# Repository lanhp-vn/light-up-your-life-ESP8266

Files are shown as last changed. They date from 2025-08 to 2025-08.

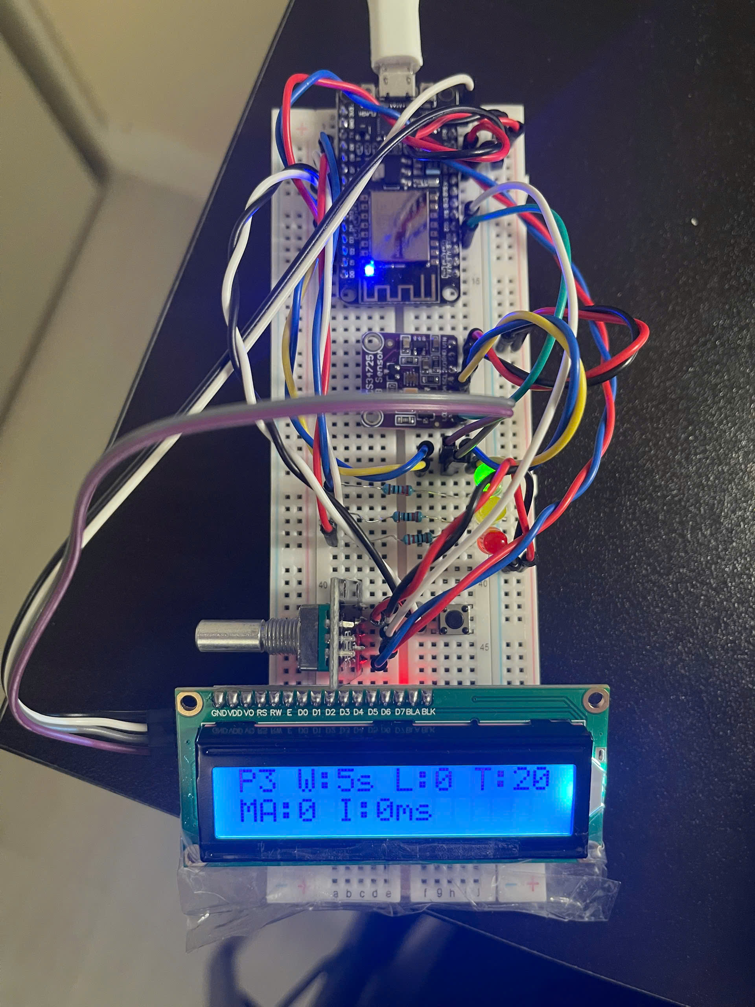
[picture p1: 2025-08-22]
Assembly.jpg

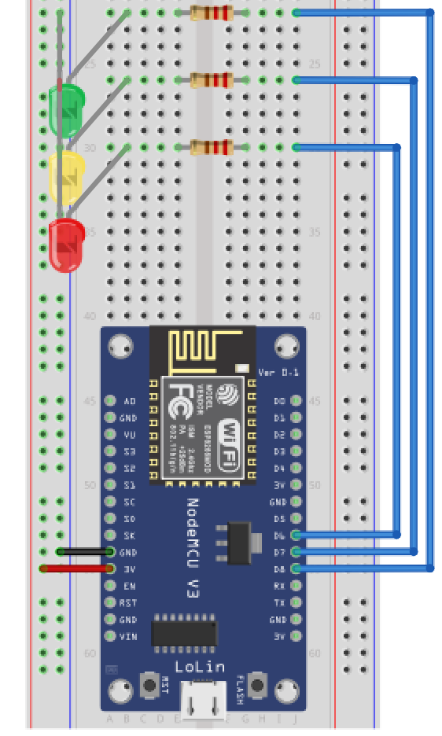
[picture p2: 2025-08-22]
Schematic/schematic_part2.png

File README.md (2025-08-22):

## Light Up Your Life (ESP8266 + TCS34725)

A multi-part IoT lab using ESP8266, Adafruit TCS34725 color/light sensor, LEDs, I2C LCD, and a rotary encoder to visualize ambient light levels and interactively tune thresholds.

Watch the demo video: [YouTube](https://youtu.be/NDT4jKHE5MQ)

### Hardware

- ESP8266 NodeMCU
- Adafruit TCS34725 RGB/clear light sensor (I2C)
- 16x2 I2C LCD (address 0x27)
- 3 x LEDs (red, yellow, green) + resistors
- 1 x momentary button
- 1 x rotary encoder with push button
- Jumper wires, breadboard

I2C bus (shared by TCS34725 and LCD):
- SCL: GPIO5 (D1)
- SDA: GPIO4 (D2)

Other connections (as used in sketches):
- Sensor LED control (`TCS_LED`): GPIO10 (FullAssembly/Part1/Part3) or GPIO0 (Part2)
- Built-in ESP LED: GPIO2 (D4) (Part3)
- Status LEDs: red=GPIO12 (D6), yellow=GPIO13 (D7), green=GPIO15 (D8)
- LCD: I2C @ 0x27 (SCL/SDA as above)
- User button (LCD/part switch): GPIO14 (D5) with INPUT_PULLUP
- Rotary encoder: CLK=GPIO2 (D4), DT=GPIO0 (D3), SW=GPIO9 (encoder push, INPUT_PULLUP)

Note: Pin choices reflect the provided sketches. On some ESP8266 boards, GPIO9/10 are SDIO pins and may be constrained. If your board does not expose them, remap to available GPIOs and update the constants accordingly.

### Project Structure

- `ArduinoSketches/Part1/Part1.ino`: Average lux over a window; drive sensor LED above threshold
- `ArduinoSketches/Part2/Part2.ino`: Classify lux into LOW/MEDIUM/HIGH; drive RGB LEDs; average window drives sensor LED
- `ArduinoSketches/Part3/Part3.ino`: Adds moving average and LED flashing rate proportional to lux; uses built-in LED to reflect average
- `ArduinoSketches/FullAssembly/FullAssembly.ino`: Integrates LCD, encoder, button to switch modes and adjust thresholds live

### Procedure

Common setup for all parts:
1. Wire I2C SCL to GPIO5 (D1), SDA to GPIO4 (D2). Power TCS34725 with 3.3V and GND.
2. If using external LEDs, connect each via a resistor to GPIO12/13/15, with common ground.
3. If using LCD, connect to the same I2C bus (address 0x27).
4. Wire the user button from GPIO14 to GND; enable `INPUT_PULLUP` in code.
5. Wire encoder CLK to GPIO2, DT to GPIO0, and SW to GPIO9 with pull-ups.

Per sketch:
- Part 1 (`Part1.ino`):
  - Window: 5 s, sample every 1 s. Threshold: 40 lux.
  - Action: Sensor LED (`TCS_LED`) turns ON if average lux ≥ threshold.
  - Observe: Serial prints Lux and Avg Lux.

- Part 2 (`Part2.ino`):
  - Thresholds: LOW ≤ 20, HIGH ≥ 70 (MEDIUM in between).
  - Actions: Green/Yellow/Red LEDs indicate LOW/MEDIUM/HIGH. Average window still controls `TCS_LED` at 40 lux.
  - Observe: Serial prints Lux and level (LOW/MEDIUM/HIGH).

- Part 3 (`Part3.ino`):
  - Adds moving average over 5 s; computes LED flash interval linearly between two points: (lux=20 → 1050 ms) and (lux=150 → 10 ms).
  - Actions: Built-in LED reflects average threshold crossing; `TCS_LED` flashes faster with higher lux when moving average > threshold.
  - Observe: Serial prints window, thresholds, Lux, Avg Lux, Moving Avg, Flash interval.

- Full Assembly (`FullAssembly.ino`):
  - LCD shows mode, window, threshold, lux, moving average, and flash interval.
  - Button on GPIO14 cycles Part 1 → 2 → 3.
  - Encoder rotates to adjust `Y_threshold` (0–100) and press to reset to base value (20).
  - Actions from Part 1–3 apply as above, with live threshold tuning.

### Expected Results

- Increasing ambient light raises measured lux. When the average over the 5 s window exceeds the configured threshold, indicator LEDs and/or the built-in LED respond accordingly.
- In Part 2, the color of the external LEDs changes to indicate LOW/MEDIUM/HIGH ranges.
- In Part 3 and Full Assembly, the sensor LED flash rate decreases (faster flashing) as lux increases, following a linear mapping between the defined points.
- The LCD in Full Assembly provides at-a-glance status, and the encoder enables on-the-fly threshold adjustment.

### Build & Upload

1. Open the desired `*.ino` in Arduino IDE (ESP8266 board package installed).
2. Select your ESP8266 board and COM port.
3. Install required libraries:
   - Adafruit TCS34725
   - Adafruit BusIO (dependency providing `Adafruit_I2CDevice.h`)
   - LiquidCrystal_I2C
4. Upload and open Serial Monitor at 115200 baud.

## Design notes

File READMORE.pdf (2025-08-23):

## EQUIPMENT LIST

Items | Model | Quantity | Power Supply
NodeMCU ESP8266 | ESP8266-12E | 1 | 4.5 to 9 VDC
RGB Color Sensor | TCS34725 | 1 | 3.3 to 5 VDC
Light Emitting Diode | 5mm Red/Yellow/Green LEDs | 3 | With resistors
Resistor | 220 Ω | 3
Push Button | Bread-board Mount | 1
Liquid-Crystal Display | I2C 1602 Serial LCD Module | 1 | 5VDC
Rotary Encoder | KY-040 | 1 | 5VDC
Table 1. Equipment list

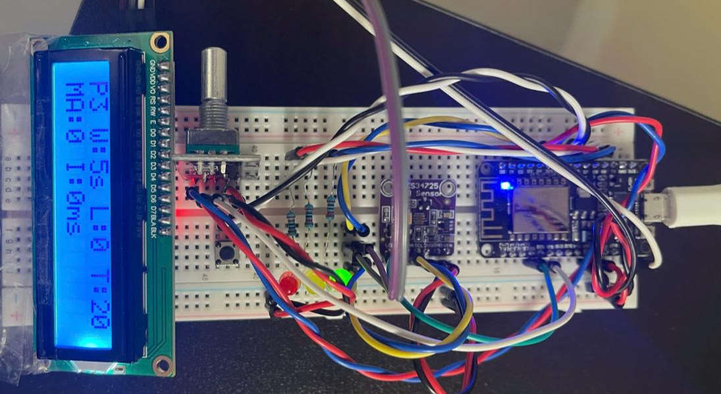
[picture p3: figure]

Figure 1. Assembly of all equipment

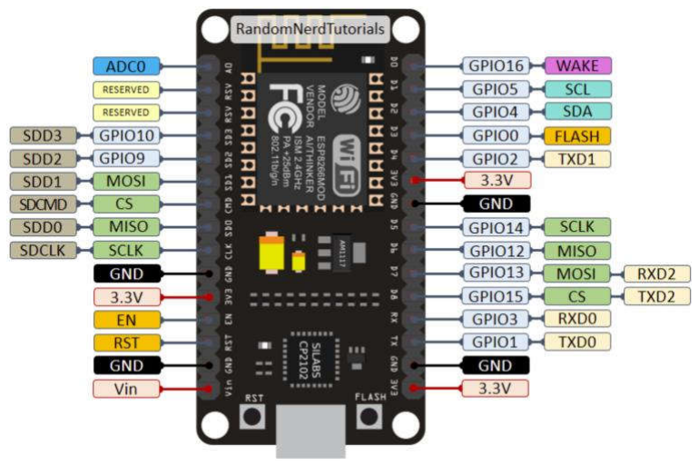
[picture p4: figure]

Figure 2. ESP8266 12-E NodeMCU pinout diagram

## PART 1

## Requirements

- Connect the RGB Light Sensor to ESP8266.
- Read sensor values once every second.
- Display the values on the IDE console window.
- Turn the onboard LED ON if the average value in a window of X seconds is higher than a threshold of Y.

## Wiring Schematic

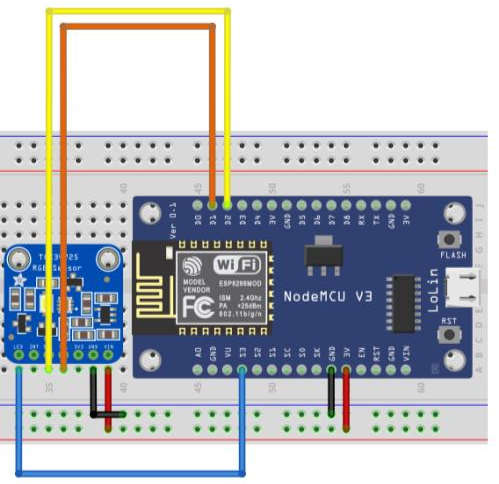
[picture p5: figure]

Figure 3. Wiring schematic for Part 1
RGB Sensor | ESP8266
GND | GND
Vin | 3.3V
SCL | D1 | GPIO5 | SCL
SDA | D2 | GPIO4 | SDA
LED | GPIO10
Table 2. Wiring connections between TCS34725 RGB sensor and ESP8266

## Code Explanation

- Include necessary libraries and define connected pins.

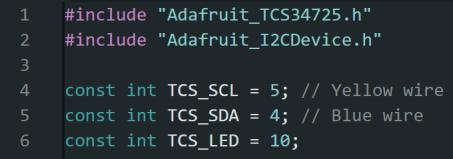
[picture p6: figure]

- Define variables and intervals for lux sampling and averaging, and set a 40-lux threshold (measured at a reasonable distance from the phone’s flash to the sensor) for LED activation.

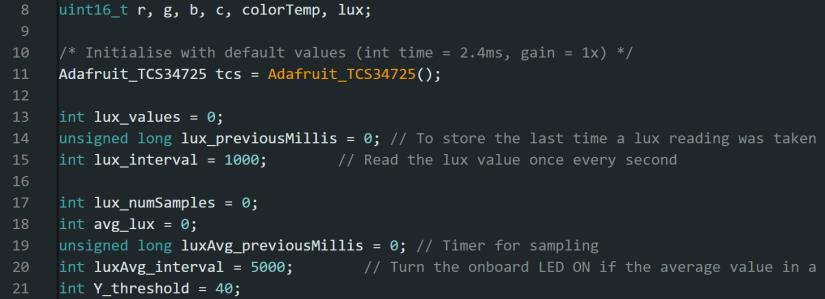
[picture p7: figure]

- Initialize serial communication; check sensor connection and print status messages, if the sensor is not found, enter an infinite loop to avoid unexpected operations.

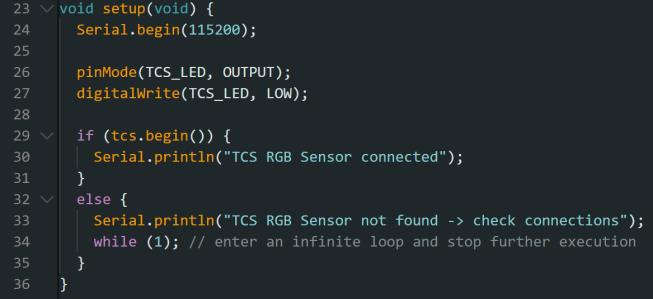
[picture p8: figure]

- Main loop that reads lux values from the sensor once every second, calculates average lux over a window of 5 seconds, and activates the LED if the average lux exceeds Y_threshold.

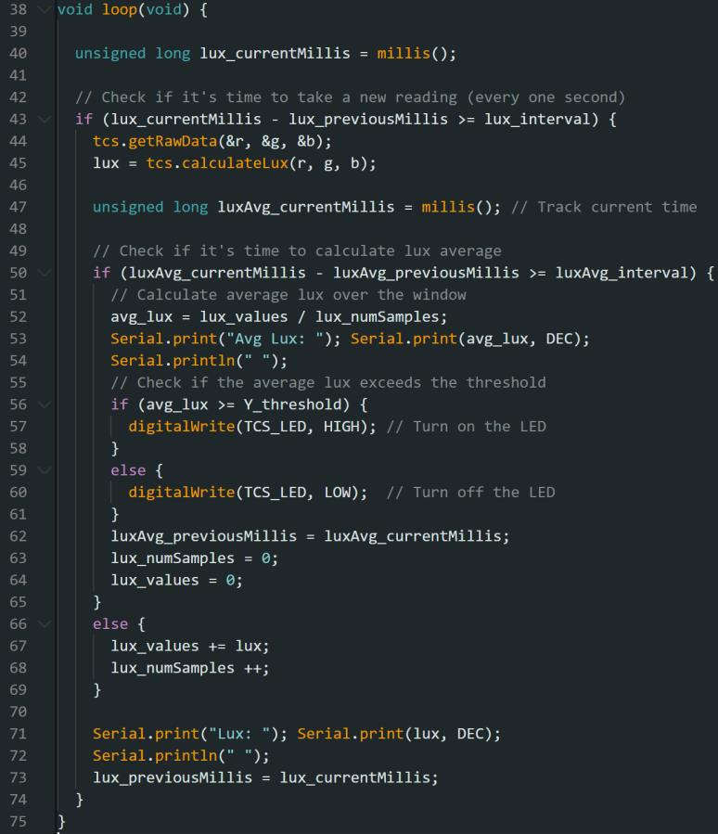
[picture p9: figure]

## PART 2

## Requirements

- Connect 3 external LEDs to ESP8266.
- Display the intensity of light from the RGB Sensor on 3 external LEDs using various patterns (e.g. low -> green LED on, medium -> yellow LED on, high -> red LED on). Document your value thresholds and justify.

## Wiring Schematic

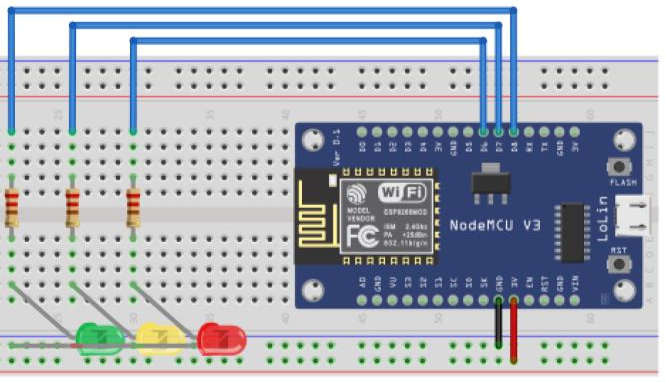
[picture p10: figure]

Figure 4. Wiring schematic for Part 2

LEDs | ESP8266
GND | GND
Red + | D6 | GPIO12
Yellow + | D7 | GPIO13
Green + | D8 | GPIO15
Use 220Ω resistor for each LED
Table 3. Wiring connections between 3 external LEDs and ESP8266

## Code Explanation

- Define variables for controlling 3 external LEDs (red, yellow, and green), representing different ranges of lux level, and define thresholds for green (below 20 - low), yellow (from 20 to 70 – medium), and red (above 70 – high) (thresholds are defined based on experimental measurements with the phone’s flash).

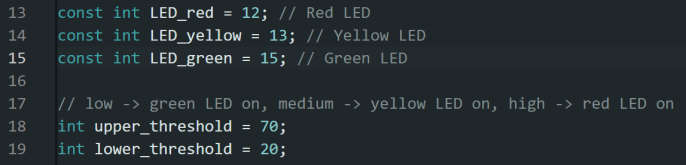
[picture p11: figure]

- Controls the green, yellow, and red LEDs based on lux levels collected once every second: green for lux below the lower threshold, yellow for values between thresholds, and red for lux above the upper threshold.

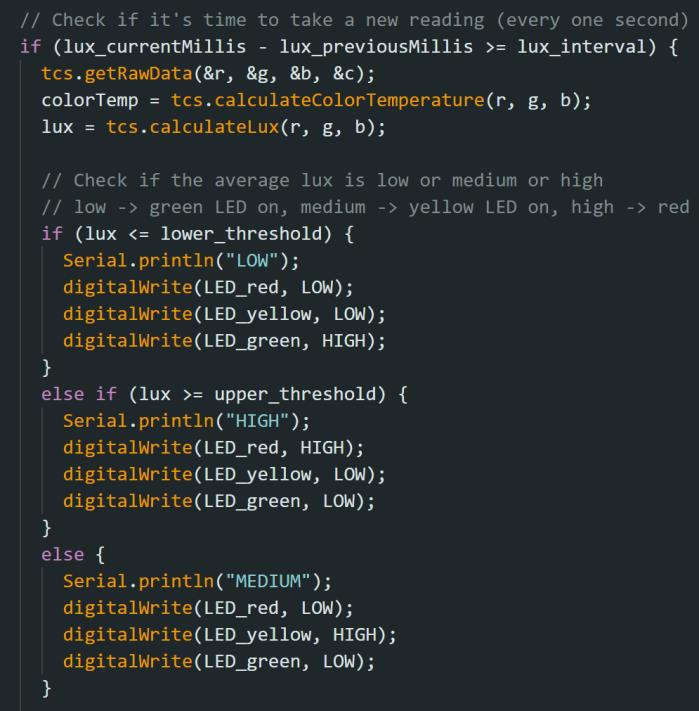
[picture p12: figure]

## PART 3

## Requirements

- Flash (instead of just ON) onboard LED if the average value in a sliding window of X seconds is higher than a threshold of Y.
- The higher the readings, the faster it flashes.

## Wiring Schematic

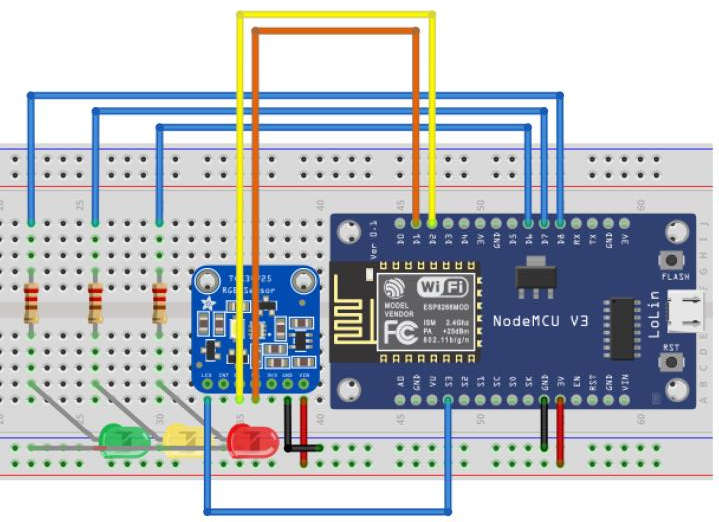
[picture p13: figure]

Figure 5. Wiring schematic for Part 3

## Code Explanation

- Calculate the moving average of lux values read every one second over a sliding window of 5 seconds by creating a circular buffer.

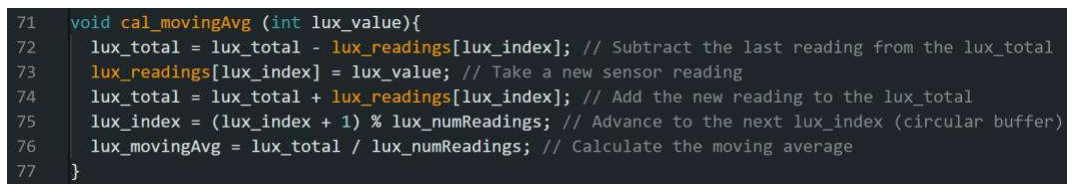
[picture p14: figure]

- Calculate the slope and intercept for a linear relationship between the lux value and the LED flashing interval, ensuring faster flashes at higher lux values.

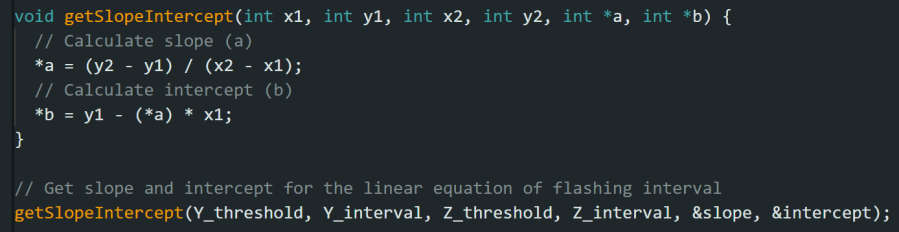
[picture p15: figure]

- Flash the onboard LED faster as the lux value increases, calculated using a linear equation, with a minimum flash interval of 10 ms.

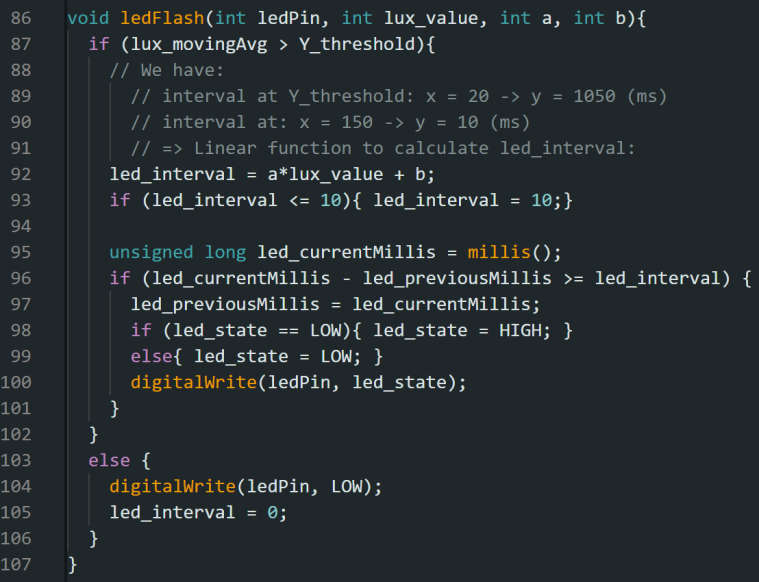
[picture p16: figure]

## OPTIONAL PART

## Requirements

- Add/use a button to switch between parts 1, 2, and 3 so you do not have to reprogram for each part.
- Display on the IDE/LED panel which part of the program is running.
- Integrate a tool to change the Y threshold externally.

## Wiring Schematic

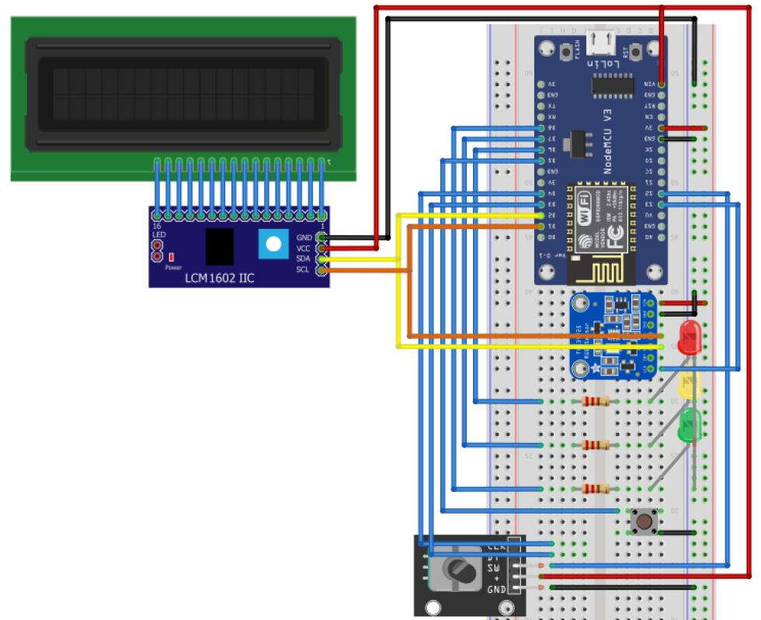
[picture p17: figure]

Figure 6. Wiring schematic for optional part

I2C LCD | ESP8266 | Encoder | ESP8266 | Button | ESP8266
GND | GND | GND | GND | NO 1 | GND
VCC | Vin (USB Power) | + | 3 | NO 2 | D5 | GPIO14
SCL | D1 | GPIO5 | SCL | SW | GPIO9
SDA | D2 | GPIO4 | SDA | DT | D3 | GPIO0
LED | GPIO10 | CLK | D4 | GPIO2
Table 4. Wiring connections between I2C LCD, rotary encoder, push button and ESP8266

## Code Explanation

- Include I2C communication library for LCD and RGB sensor (Wire.h), and control the LCD (LiquidCrystal_I2C).
- Check if the main button was pressed and released. If it was, the part variable is incremented cyclically to switch between 3 different parts using Switch-Case logic.

- If the rotary encoder's state changes, the code checks which direction the knob was rotated (by comparing encod_DT and encod_CLK). Based on the rotation, the Y_threshold is increased or decreased within a range of 0 to 100 (self-defined). And if the encoder button is pressed, the Y_threshold is reset to its initial value (Y_threshold_base = 20).

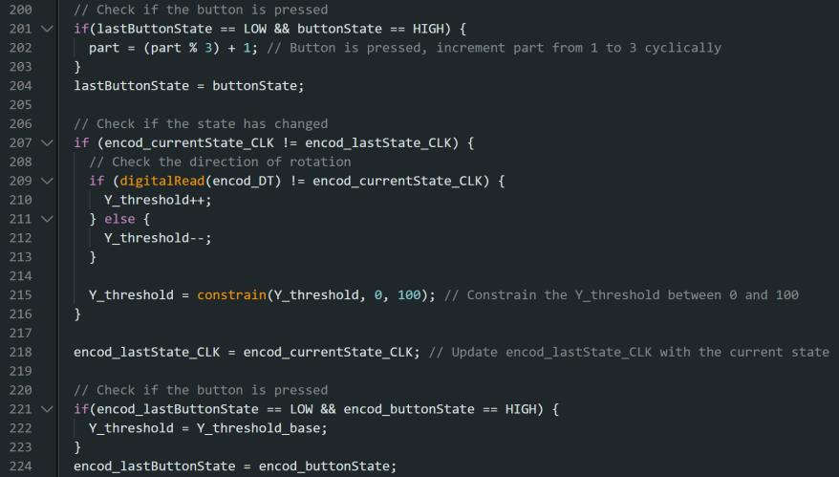
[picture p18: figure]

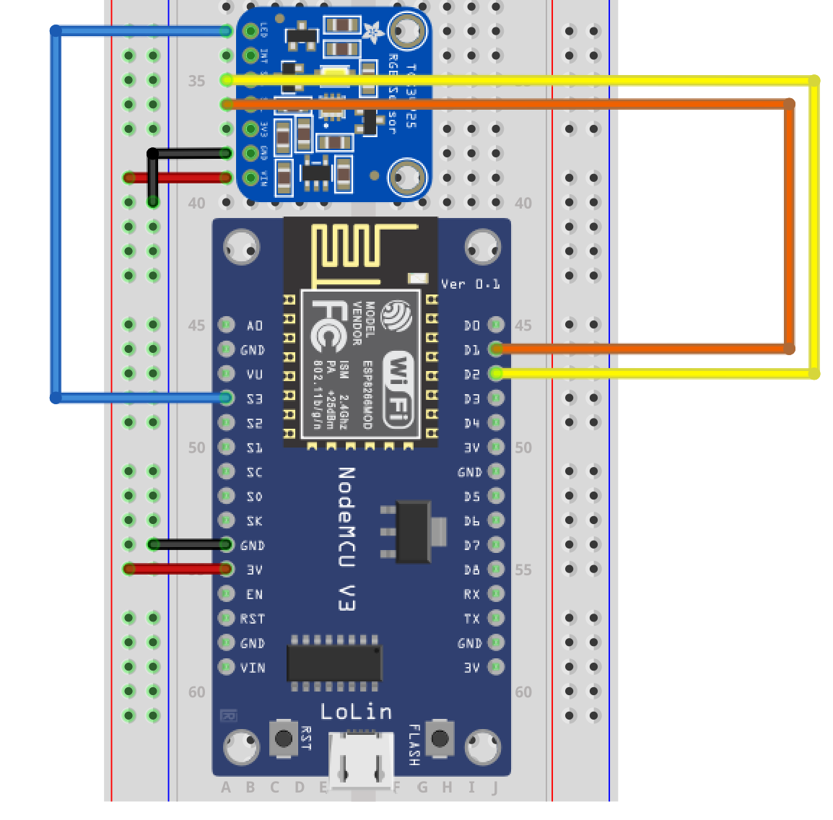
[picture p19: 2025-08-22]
Schematic/schematic_part1.png

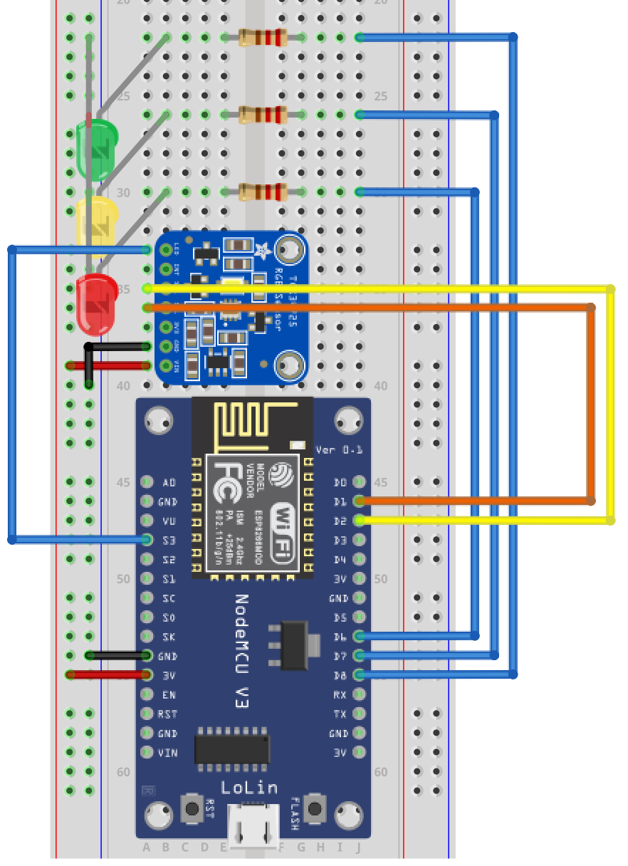
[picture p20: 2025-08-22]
Schematic/schematic_part3.png

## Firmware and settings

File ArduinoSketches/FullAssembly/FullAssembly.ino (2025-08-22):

#include "Adafruit_TCS34725.h"
#include "Adafruit_I2CDevice.h"
#include "Adafruit_TCS34725.h"
#include "LiquidCrystal_I2C.h"
#include "Wire.h"

// LCD configuration
LiquidCrystal_I2C lcd(0x27, 16, 2);  // Address 0x27, 16 columns, 2 rows

// Initialise with default values (int time = 2.4ms, gain = 1x)
Adafruit_TCS34725 tcs = Adafruit_TCS34725();
// Adafruit_TCS34725 tcs = Adafruit_TCS34725(TCS34725_INTEGRATIONTIME_50MS, TCS34725_GAIN_4X);

const int TCS_LED = 10;

uint16_t r, g, b, c, colorTemp, lux;

const int LED_red = 12; // Red LED
const int LED_yellow = 13; // Yellow LED
const int LED_green = 15; // Green LED

const int encod_CLK = 2;
const int encod_DT = 0;
const int encod_button = 9;

const int button = 14; // Button for LCD Control

int buttonState = 0;
int lastButtonState = 0;
int part = 0;

int encod_lastState_CLK;
int encod_currentState_CLK;
int encod_buttonState = 0;
int encod_lastButtonState = 0;

// low -> green LED on, medium -> yellow LED on, high -> red LED on
int upper_threshold = 70;
int lower_threshold = 20;
String status;

int lux_values = 0;
unsigned long lux_previousMillis = 0; // To store the last time a lux reading was taken
int lux_interval = 1000; // Read the lux value once every second

int lux_numSamples = 0;
int lux_avg = 0;
unsigned long luxAvg_previousMillis = 0; // Timer for sampling
int luxAvg_interval = 5000; // Turn the onboard LED ON if the average value in a window of X seconds is higher than a threshold of Y 
int luxAvg_interval_sec = luxAvg_interval / 1000;

// We have:
  // interval at Y_threshold: x = 20 -> y = 1050 (ms)
  // interval at Z_threshold: x = 150 -> y = 10 (ms)
int Y_threshold = 20;
int Y_threshold_base = 20;
int Y_interval = 1050;
int Z_threshold = 150;
int Z_interval = 10;

int lux_numReadings; // Number of readings in a sliding window of X seconds
int *lux_readings;  // Pointer for dynamic array
int lux_index = 0; // Index of the current reading
int lux_total = 0; // Sum of the readings
int lux_movingAvg = 0; // The calculated moving average

bool led_state = LOW;
int led_interval = 0;
int slope, intercept;
unsigned long led_previousMillis = 0;  // will store last time LED was updated

void cal_movingAvg (int lux_value){
  lux_total = lux_total - lux_readings[lux_index]; // Subtract the last reading from the lux_total
  lux_readings[lux_index] = lux_value; // Take a new sensor reading
  lux_total = lux_total + lux_readings[lux_index]; // Add the new reading to the lux_total
  lux_index = (lux_index + 1) % lux_numReadings; // Advance to the next lux_index (circular buffer)
  lux_movingAvg = lux_total / lux_numReadings; // Calculate the moving average
}

void getSlopeIntercept(int x1, int y1, int x2, int y2, int *a, int *b) {
  // Calculate slope (a)
  *a = (y2 - y1) / (x2 - x1);
  // Calculate intercept (b)
  *b = y1 - (*a) * x1;
}

void part1(int ledPin, int lux_value){
  unsigned long luxAvg_currentMillis = millis(); // Track current time
  // Check if it's time to calculate lux average
  if (luxAvg_currentMillis - luxAvg_previousMillis >= luxAvg_interval) {
    luxAvg_previousMillis = luxAvg_currentMillis;
    // Calculate average lux over the window
    lux_avg = lux_values / lux_numSamples;
    // Check if the average lux exceeds the threshold
    if (lux_avg >= Y_threshold) { digitalWrite(ledPin, HIGH); } // Turn on the ESP LED
    else { digitalWrite(ledPin, LOW); } // Turn off the ESP LED
    lux_numSamples = 0;
    lux_values = 0;
  }
  else {
    lux_values += lux_value;
    lux_numSamples ++;
  }
}

void part2 (int lux_value){
  // Check if the average lux is low or medium or high
  // low -> green LED on, medium -> yellow LED on, high -> red LED on
  if (lux <= lower_threshold) {
    // Serial.println("LOW");
    digitalWrite(LED_red, LOW);
    digitalWrite(LED_yellow, LOW);
    digitalWrite(LED_green, HIGH);
    status = "low";
  }
  else if (lux >= upper_threshold) {
    // Serial.println("HIGH");
    digitalWrite(LED_red, HIGH);
    digitalWrite(LED_yellow, LOW);
    digitalWrite(LED_green, LOW);
    status = "high";
  }
  else {
    // Serial.println("MEDIUM");
    digitalWrite(LED_red, LOW);
    digitalWrite(LED_yellow, HIGH);
    digitalWrite(LED_green, LOW);
    status = "norm";
  }
}

void part3(int ledPin, int lux_value, int a, int b){
  if (lux_movingAvg > Y_threshold){
    // Linear function to calculate led_interval: 
    led_interval = a*lux_value + b;
    if (led_interval <= 10){ led_interval = 10;}

    unsigned long led_currentMillis = millis();
    if (led_currentMillis - led_previousMillis >= led_interval) {
      led_previousMillis = led_currentMillis;
      if (led_state == LOW){ led_state = HIGH; }
      else{ led_state = LOW; }
      digitalWrite(ledPin, led_state);
    }
  }
  else {
    digitalWrite(ledPin, LOW);
    led_interval = 0;
  }
}

void setup() {
  Serial.begin(115200);

  // Initialize LCD
  lcd.init();
  lcd.backlight();
  lcd.clear();

  pinMode(TCS_LED, OUTPUT);
  pinMode(LED_red, OUTPUT);
  pinMode(LED_yellow, OUTPUT);
  pinMode(LED_green, OUTPUT);
  pinMode(button, INPUT_PULLUP);
  pinMode(encod_CLK, INPUT);
  pinMode(encod_DT, INPUT);
  pinMode(encod_button, INPUT_PULLUP);

  digitalWrite(TCS_LED, LOW);
  digitalWrite(LED_red, LOW);
  digitalWrite(LED_yellow, LOW);
  digitalWrite(LED_green, LOW);

  lux_numReadings = luxAvg_interval / lux_interval;  // Calculate at runtime
  lux_readings = new int[lux_numReadings];  // Dynamically allocate memory for the array

  encod_lastState_CLK = digitalRead(encod_CLK);

  // Initialize the lux array to 0
  for (int i = 0; i < lux_numReadings; i++) {
  lux_readings[i] = 0;
  }

  if (tcs.begin()) {
    Serial.println("TCS RGB Sensor connected");
  }
  else {
    Serial.println("TCS RGB Sensor not found -> check connections");
    while (1); // enter an infinite loop and stop further execution
  }
}

void loop() {
  tcs.getRawData(&r, &g, &b, &c);
  lux = tcs.calculateLux(r, g, b);
  buttonState = digitalRead(button);
  encod_buttonState = digitalRead(encod_button);
  encod_currentState_CLK = digitalRead(encod_CLK);

  // Check if the button is pressed
  if(lastButtonState == LOW && buttonState == HIGH) {
    part = (part % 3) + 1; // Button is pressed, increment part from 1 to 3 cyclically
  }
  lastButtonState = buttonState;

  // Check if the state has changed
  if (encod_currentState_CLK != encod_lastState_CLK) {
    // Check the direction of rotation
    if (digitalRead(encod_DT) != encod_currentState_CLK) {
      Y_threshold++;
    } else {
      Y_threshold--;
    }

    Y_threshold = constrain(Y_threshold, 0, 100); // Constrain the Y_threshold between 0 and 100
  }

  encod_lastState_CLK = encod_currentState_CLK; // Update encod_lastState_CLK with the current state

  // Check if the button is pressed
  if(encod_lastButtonState == LOW && encod_buttonState == HIGH) {
    Y_threshold = Y_threshold_base;
  }
  encod_lastButtonState = encod_buttonState;

  unsigned long lux_currentMillis = millis();
  
  // Switch case based on part
  switch (part) {

    case 1:
      
      // Check if it's time to take a new reading (every one second)
      if (lux_currentMillis - lux_previousMillis >= lux_interval) {
        lux_previousMillis = lux_currentMillis;

        part1(TCS_LED, lux);

        // Display information on LCD
        lcd.clear();
        lcd.setCursor(0, 0); // First row
        lcd.print("P"); lcd.print(part); 
        lcd.print(" W:"); lcd.print(luxAvg_interval_sec); lcd.print("s");
        lcd.print(" T:"); lcd.print(Y_threshold); 

        lcd.setCursor(0, 1); // Second row
        lcd.print("L:"); lcd.print(lux); 
        lcd.print(" A:"); lcd.print(lux_avg);
      
        Serial.print("Part: "); Serial.print(part, DEC); Serial.print(" | ");
        Serial.print("Window: "); Serial.print(luxAvg_interval_sec, DEC); Serial.print("s | ");
        Serial.print("Threshold: "); Serial.print(Y_threshold, DEC); Serial.print(" | ");
        Serial.print("Lux: "); Serial.print(lux, DEC); Serial.print(" | ");
        Serial.print("Avg Lux: "); Serial.print(lux_avg, DEC);
        Serial.println(" ");
      }
      break;

    case 2:
      // Take a new lux reading every one second
      if (lux_currentMillis - lux_previousMillis >= lux_interval) {
        lux_previousMillis = lux_currentMillis;

        part2(lux);

        // Display information on LCD
        lcd.clear();
        lcd.setCursor(0, 0);  // First row
        lcd.print("P"); lcd.print(part); 
        lcd.print(" T:"); lcd.print(lower_threshold); lcd.print("-"); lcd.print(upper_threshold); 

        lcd.setCursor(0, 1);  // Second row
        lcd.print("L:"); lcd.print(lux); 
        lcd.print(" Lv:"); lcd.print(status);

        Serial.print("Part: "); Serial.print(part, DEC); Serial.print(" | ");
        Serial.print("Upper Threshold: "); Serial.print(upper_threshold, DEC); Serial.print(" | ");
        Serial.print("Lower Threshold: "); Serial.print(lower_threshold, DEC); Serial.print(" | ");
        Serial.print("Lux: "); Serial.print(lux, DEC); Serial.print(" | ");
        Serial.print("Status: "); Serial.print(status);
        Serial.println(" ");
      }
      break;

    case 3:
      // Get slope and intercept for the linear equation of flashing interval
      getSlopeIntercept(Y_threshold, Y_interval, Z_threshold, Z_interval, &slope, &intercept);
      part3(TCS_LED, lux, slope, intercept);
      // Take a new lux reading every one second
      if (lux_currentMillis - lux_previousMillis >= lux_interval) {
        lux_previousMillis = lux_currentMillis;

        cal_movingAvg (lux);

        // Display information on LCD
        lcd.clear();
        lcd.setCursor(0, 0); // First row
        lcd.print("P"); lcd.print(part);
        lcd.print(" "); lcd.print(luxAvg_interval_sec); lcd.print("s");
        lcd.print(" L:"); lcd.print(lux);
        lcd.print(" T:"); lcd.print(Y_threshold);
        
        lcd.setCursor(0, 1); // Second row
        lcd.print("MA:"); lcd.print(lux_movingAvg);
        lcd.print(" I:"); lcd.print(led_interval); lcd.print("ms");

        Serial.print("Part: "); Serial.print(part, DEC); Serial.print(" | ");
        Serial.print("Window: "); Serial.print(luxAvg_interval_sec, DEC); Serial.print("s | ");
        Serial.print("Threshold: "); Serial.print(Y_threshold, DEC); Serial.print(" | ");
        Serial.print("Lux: "); Serial.print(lux, DEC); Serial.print(" | ");
        Serial.print("Moving Avg Lux: "); Serial.print(lux_movingAvg, DEC); Serial.print(" | ");
        Serial.print("Flashing Interval: "); Serial.print(led_interval, DEC); Serial.print("ms | ");
        Serial.println(" ");
      }
      break;
  }
}
